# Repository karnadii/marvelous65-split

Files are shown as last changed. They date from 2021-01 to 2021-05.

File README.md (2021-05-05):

# Marvelous65 Split
ALL THE FILES MOVED TO https://github.com/karnadii/marvelous65

A split version of my marvelous65 keyboard. powered by pro micro or any compatible footprint like nice!nano and nrfmicro. This keyboard is wireless ready, I have added JST-XH connection for battery and an on off switch for the battery connection. It have encoder and oled on both side. also I have added underglow footprint if you want to add underglow in your keyboard. 

## Layout
try it at [KLE](http://www.keyboard-layout-editor.com/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'&_a:6&w:2.25%3B&=Enter&_x:1.75&a:7%3B&=%3B&@_w:1.25%3B&=&=&_x:1.75&a:6&w:2.25%3B&=Shift&_a:4%3B&=Z&=X&=C&=V&=B&_x:1%3B&=N&=M&=%3C%0A,&=%3E%0A.&=%3F%0A%2F%2F&_a:6&w:1.75%3B&=Shift%3B&@_y:-0.75&x:19.25&a:7%3B&=%E2%86%91%3B&@_y:-0.25&x:4&a:6&w:1.25%3B&=Ctrl&_w:1.25%3B&=Win&_w:1.25%3B&=Alt&_a:7&w:2.25%3B&=&_a:6&w:1.25%3B&=Fn2&_x:1&a:7&w:2.75%3B&=&_a:6%3B&=Alt&=Fn&=Ctrl%3B&@_y:-0.75&x:18.25&a:7%3B&=%E2%86%90&=%E2%86%93&=%E2%86%92%3B&@_x:15&w:1.5%3B&=&_w:1.5%3B&=)
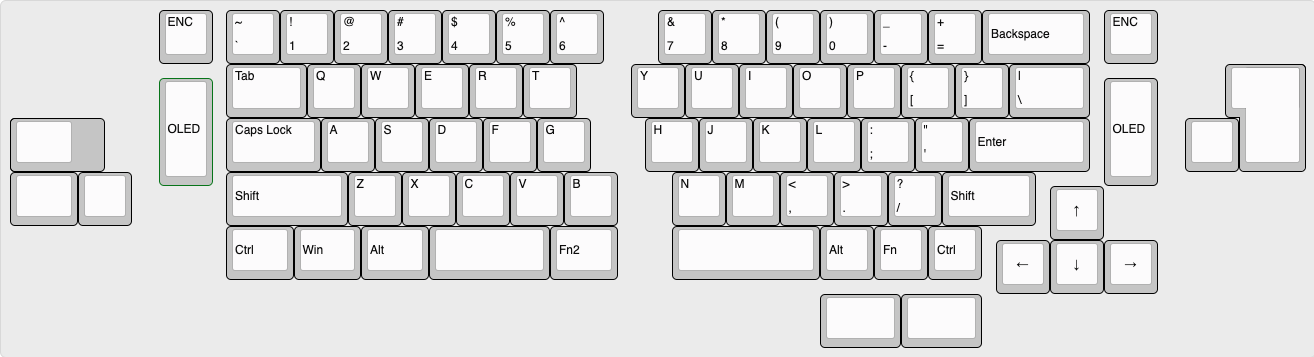
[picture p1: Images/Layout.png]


## Features
- Rotary Encoder
- 128x32 Oled display
- Wireless ready
- Promicro footprint 
- Optional RGB underglow (have to solder directly to mcu or desolder some resistor for pro micro. nice!nano and nrfmicro you can use unused pin)

## Firmware
For promicro you can use QMK and ZMK for wireless

## Case
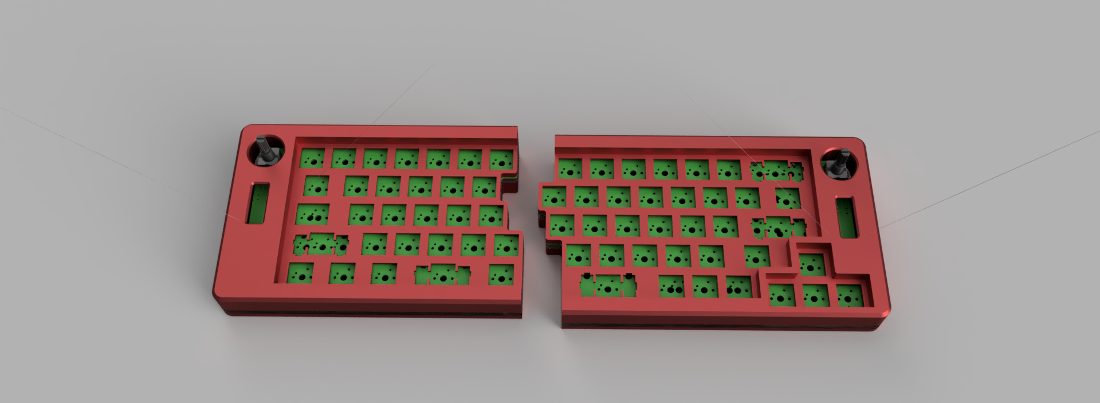
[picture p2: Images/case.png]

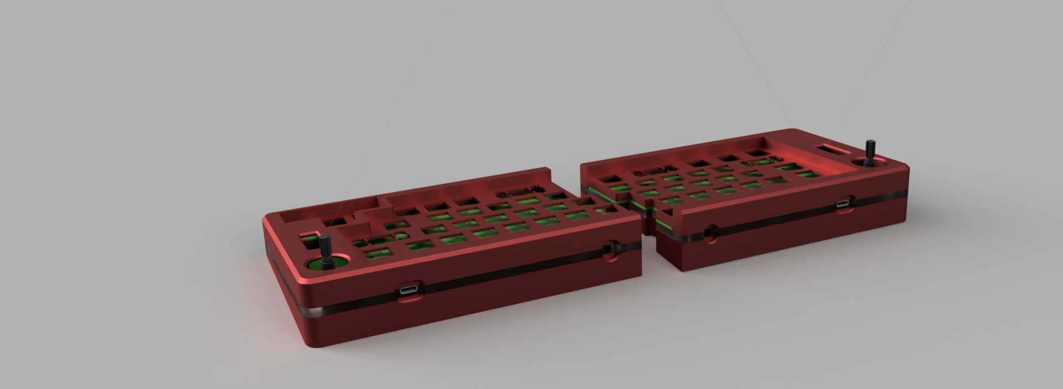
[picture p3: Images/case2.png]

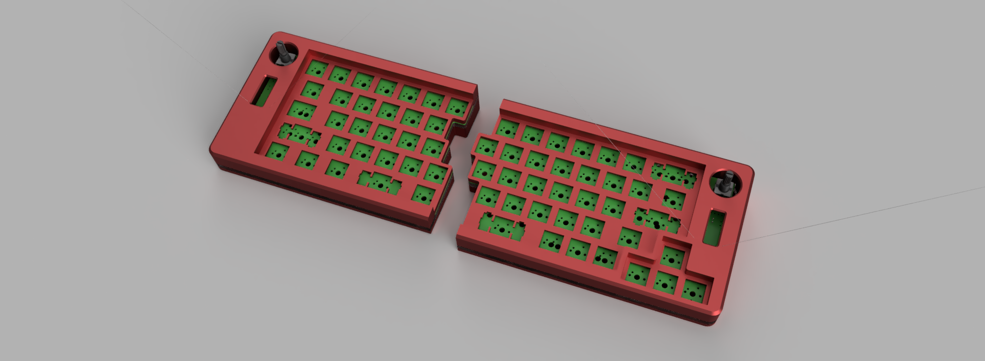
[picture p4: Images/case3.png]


## PCB
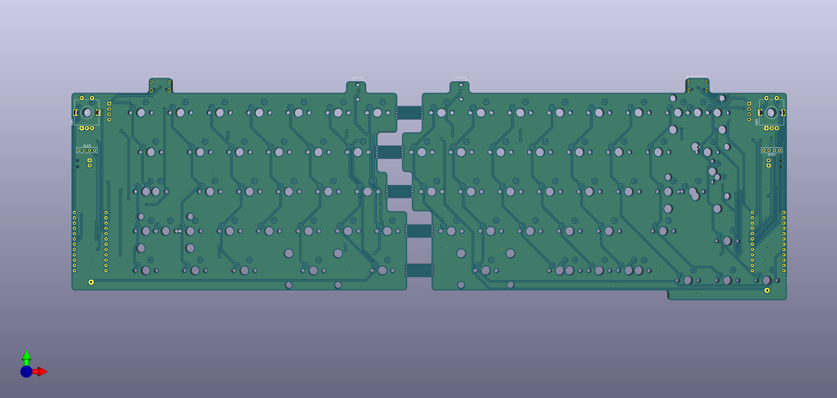
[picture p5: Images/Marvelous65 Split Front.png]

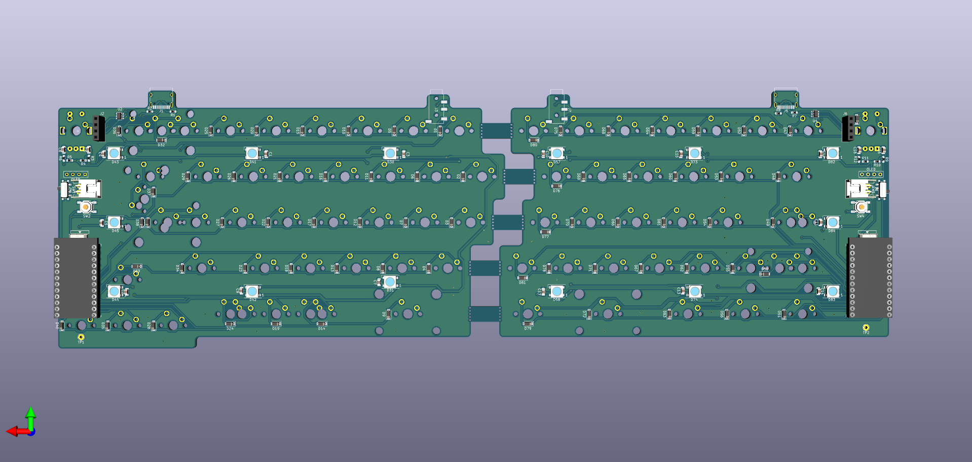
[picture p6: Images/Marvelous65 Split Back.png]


## Reference
This is my reference when designing the pcb
- https://github.com/Nicell/nice60

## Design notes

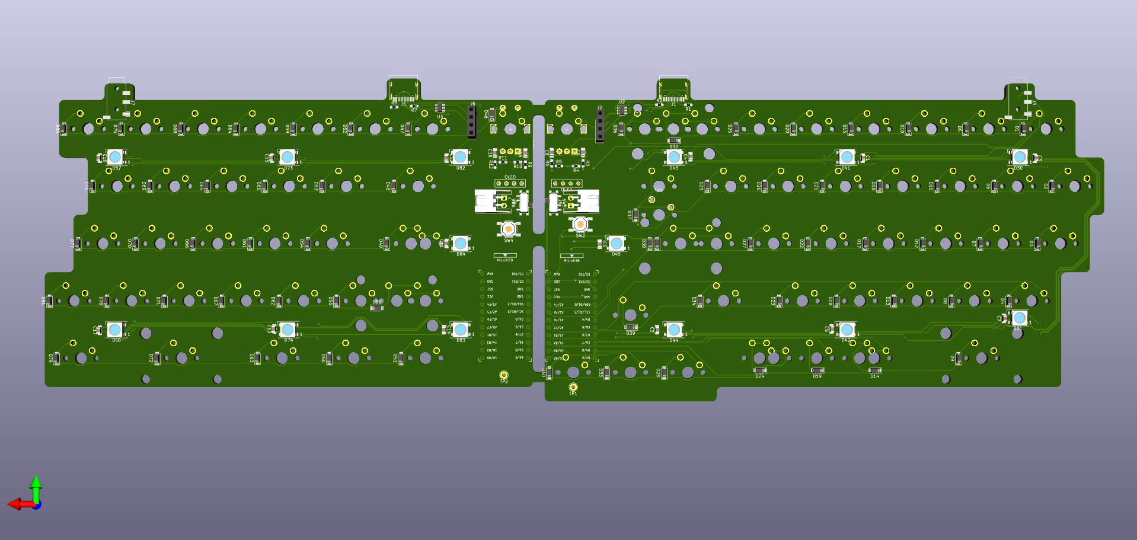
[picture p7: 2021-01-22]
Images/Marvelous65 Split.png

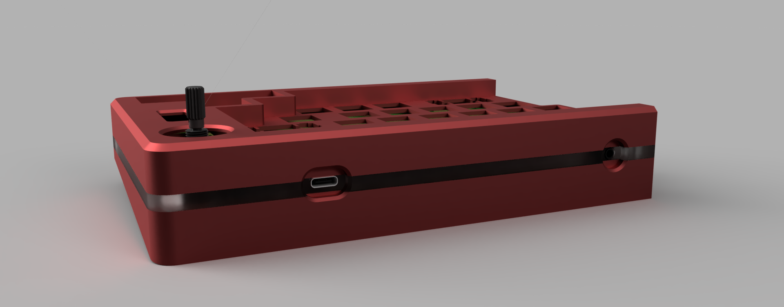
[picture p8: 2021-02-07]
PCB/Marvelous65_Split_Case_2021-Feb-07_12-52-04AM-000_CustomizedView30927780068.png

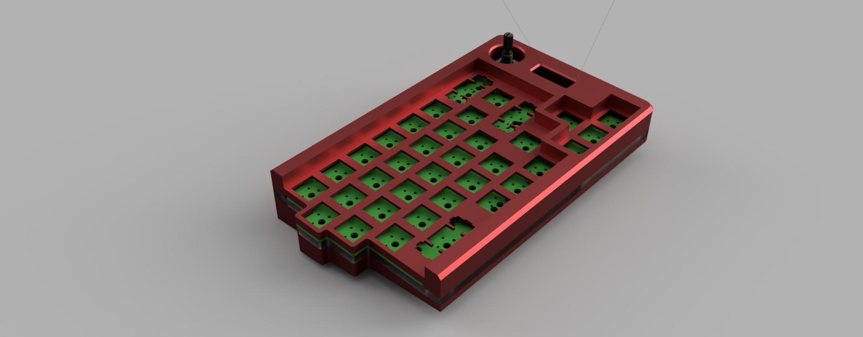
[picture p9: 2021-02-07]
PCB/Marvelous65_Split_Case_2021-Feb-07_12-53-03AM-000_CustomizedView2157800491.png

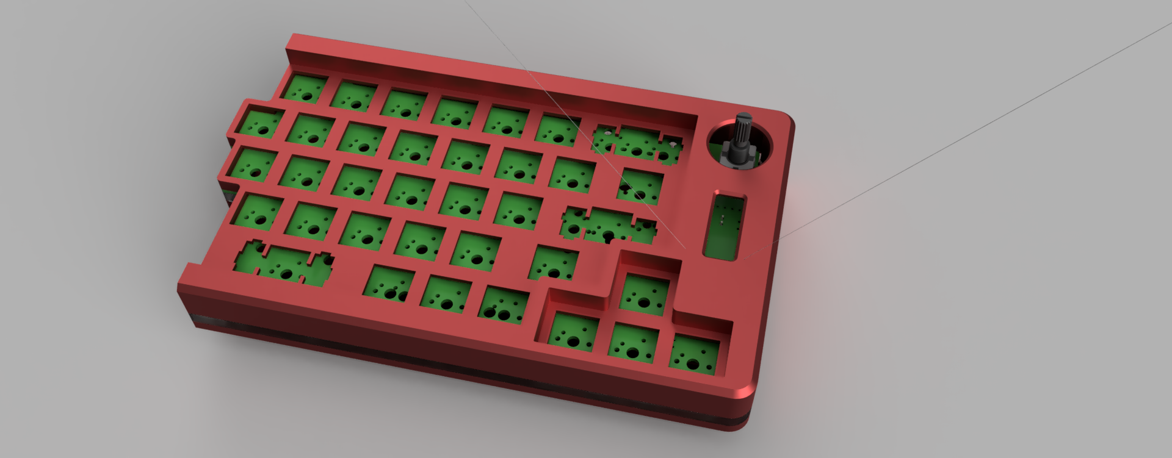
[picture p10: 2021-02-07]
PCB/Marvelous65_Split_Case_2021-Feb-07_12-50-50AM-000_CustomizedView4176303397.png

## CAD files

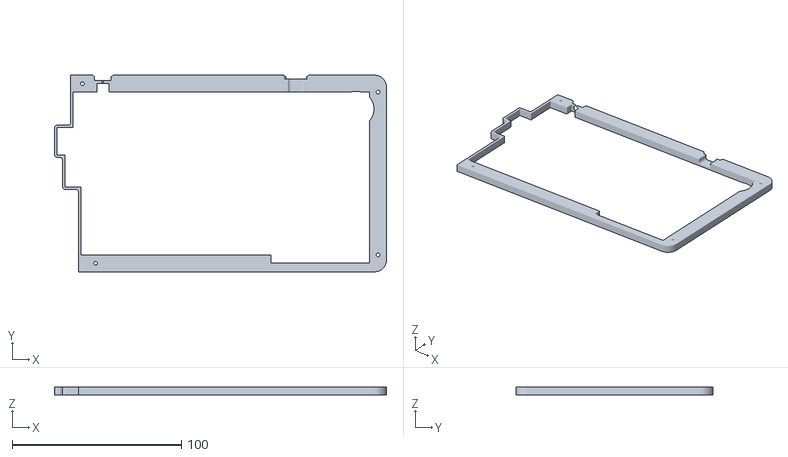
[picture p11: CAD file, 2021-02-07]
Case/Right middle case.stl
196.2 x 116.2 x 5.00

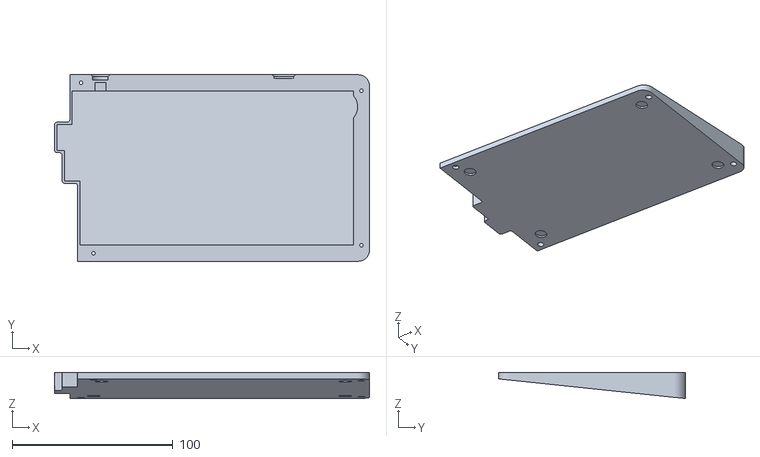
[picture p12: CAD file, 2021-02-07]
Case/Right bottom case.stl
196.2 x 116.2 x 16.2

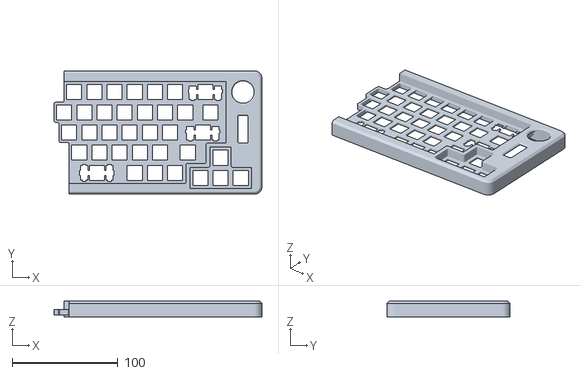
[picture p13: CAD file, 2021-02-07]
PCB/Top case.stl
196.2 x 116.2 x 14.7

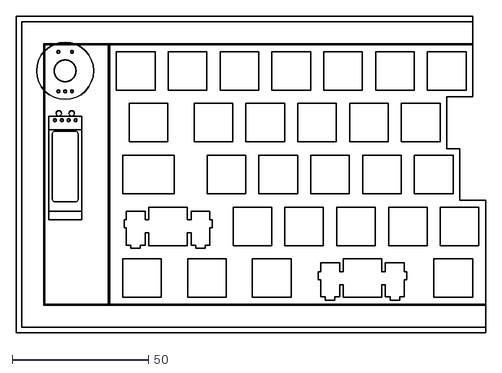
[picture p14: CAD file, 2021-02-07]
Sketch/Left Plate.dxf
172.4 x 116.3

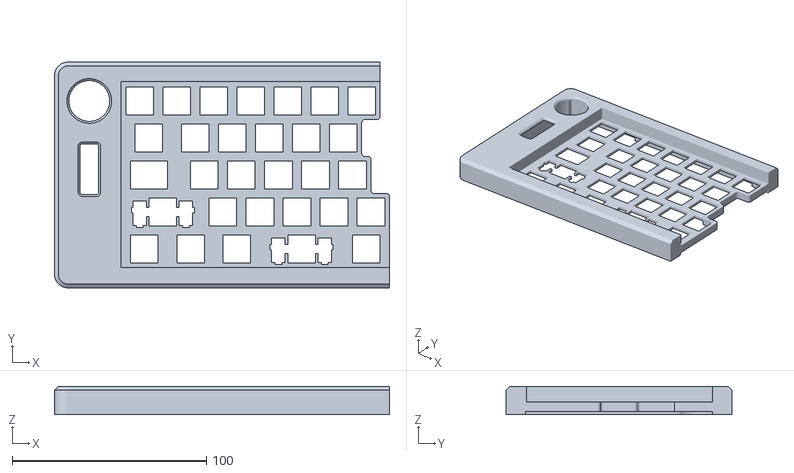
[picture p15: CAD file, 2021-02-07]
Case/Left top case.stl
172.4 x 116.3 x 14.6

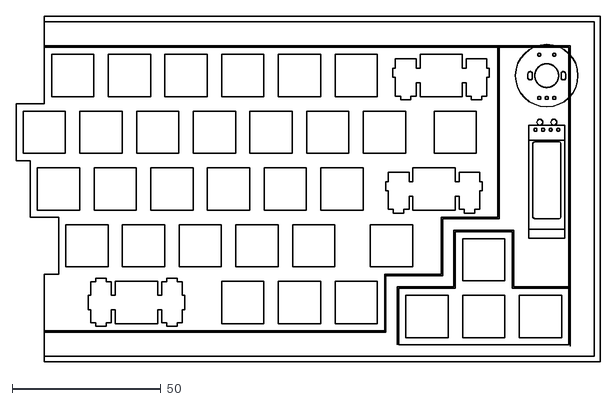
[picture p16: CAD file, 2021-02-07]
Sketch/Right plate.dxf
196.2 x 116.2

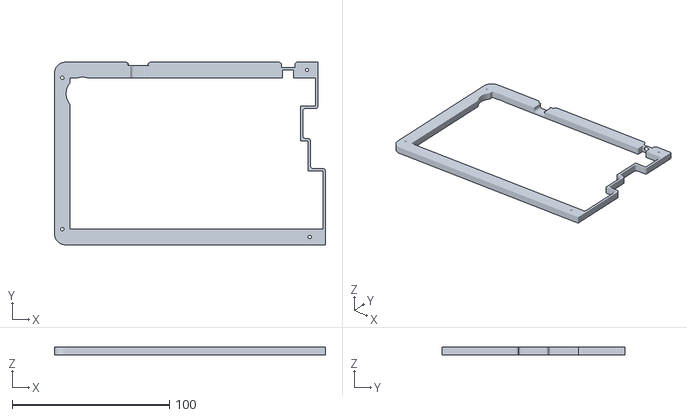
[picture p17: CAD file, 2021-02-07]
Case/Left middle case.stl
172.4 x 116.3 x 5.00

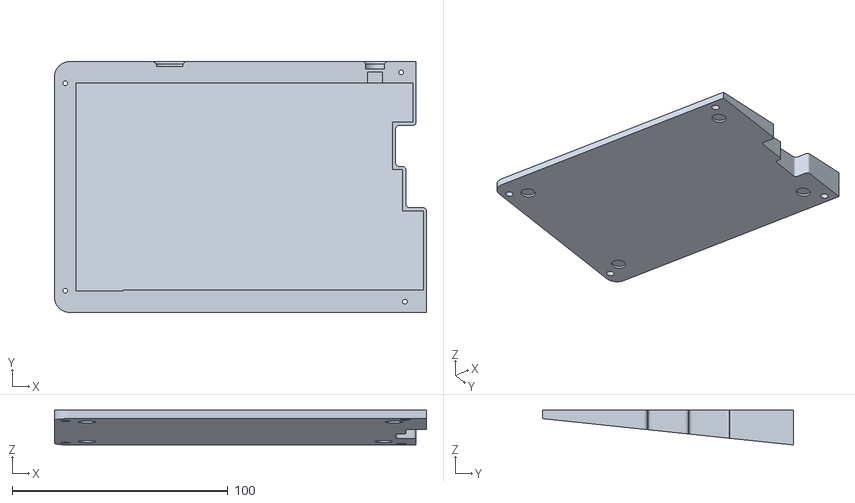
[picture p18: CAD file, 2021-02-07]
Case/left bottom case.stl
172.4 x 116.3 x 16.2

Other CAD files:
PCB/middle case.stl
Sketch/Right platsse.dwg
PCB/bottom case.stl
Case/Right Top case.stl
Sketch/Left Plate.dwg
Sketch/Right plate.dwg

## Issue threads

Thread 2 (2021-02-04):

Flipped connection on usb 4x1 pin

karnadii, 2021-02-04:
The square pad should be ground and not vbus. It is fine lea ing it as is. Bit it would be better to follow good practice.

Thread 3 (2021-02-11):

Move reset button and battery connector

karnadii, 2021-02-11:
The reset button, battery switch, and battery connector. It is hard to reach once assembled

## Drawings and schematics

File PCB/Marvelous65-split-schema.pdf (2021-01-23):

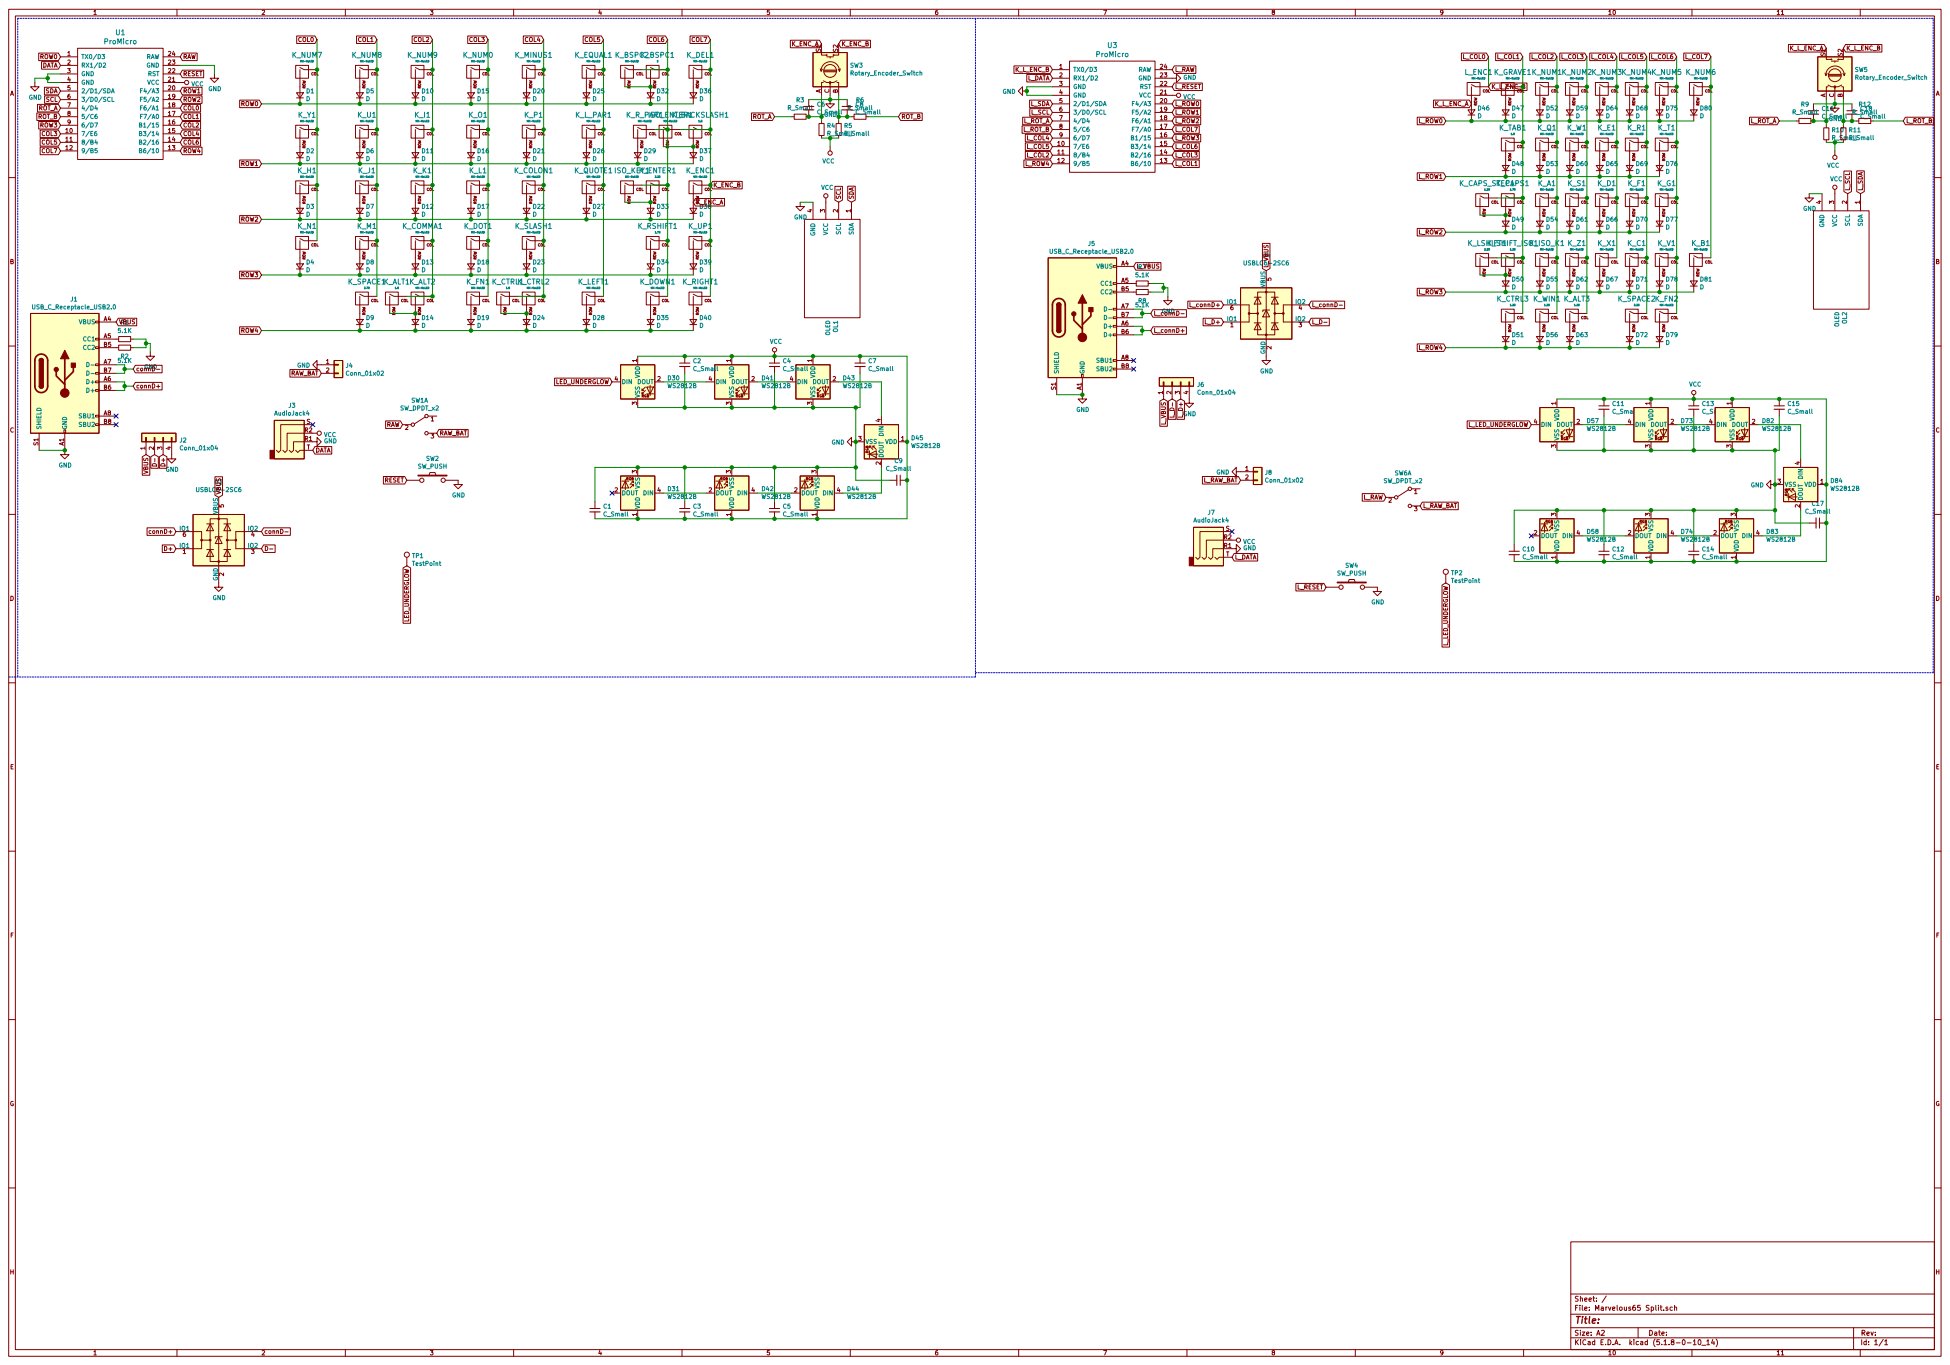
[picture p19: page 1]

MX-NoLED COL ROW

K_L_ENC_B

File: Marvelous65 Split.sch Sheet: /

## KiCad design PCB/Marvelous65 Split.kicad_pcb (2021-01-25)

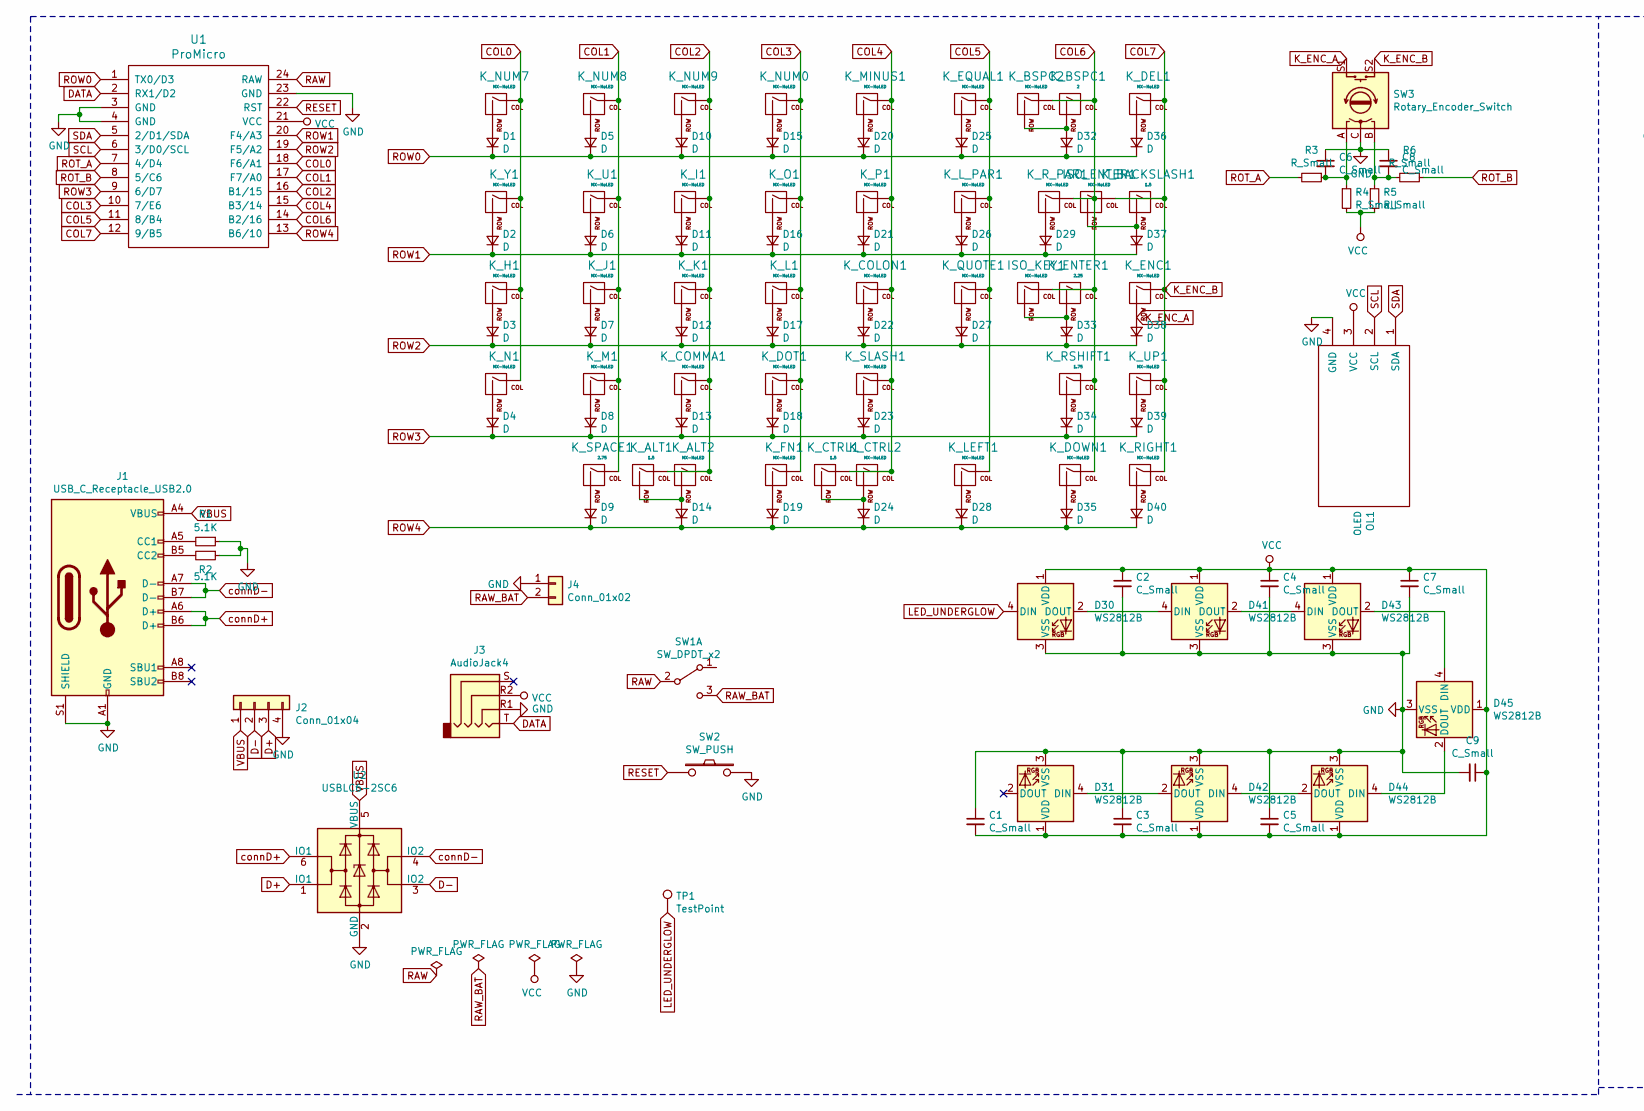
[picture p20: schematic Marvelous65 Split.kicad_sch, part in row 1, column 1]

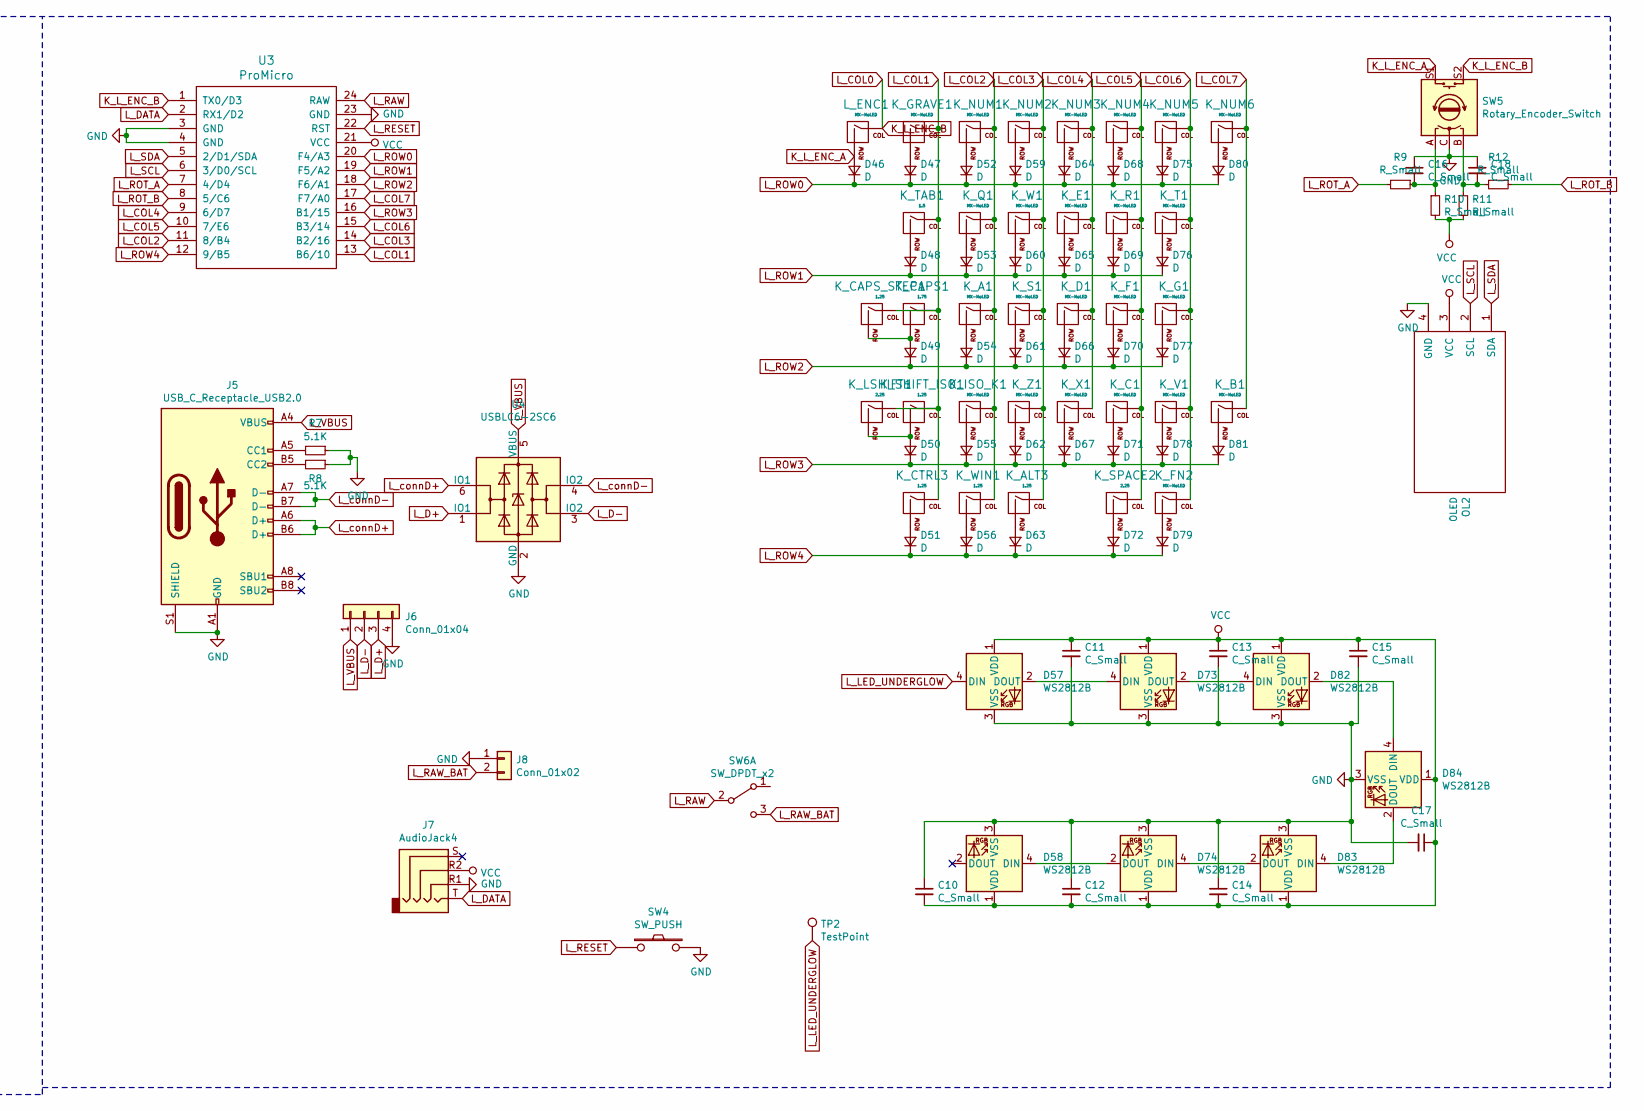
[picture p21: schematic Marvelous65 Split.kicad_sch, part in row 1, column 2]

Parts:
C1, C2, C3, C4, C5, C6, C7, C8, C9, C10, C11, C12, C13, C14, C15, C16, C17, C18: C_Small; C_0805_2012Metric_Pad1.15x1.40mm_HandSolder
D1, D2, D3, D4, D5, D6, D7, D8, D9, D10, D11, D12, D13, D14, D15, D16, D17, D18, D19, D20, D21, D22, D23, D24, D25, D26, D27, D28, D29, D32, D33, D34, D35, D36, D37, D38, D39, D40, D46, D47, D48, D49, D50, D51, D52, D53, D54, D55, D56, D59, D60, D61, D62, D63, D64, D65, D66, D67, D68, D69, D70, D71, D72, D75, D76, D77, D78, D79, D80, D81: D; D_SOD-123
D30, D31, D41, D42, D43, D44, D45, D57, D58, D73, D74, D82, D83, D84: WS2812B; LED_WS2812B_PLCC4_5.0x5.0mm_P3.2mm
ISO_ENTER1: MX-NoLED; MXOnly-ISO-ROTATED-ReversedStabilizers-NoLED
ISO_KEY1: MX-NoLED; MXOnly-1U-NoLED
J1, J5: USB_C_Receptacle_USB2.0; USB_C_Receptacle_HRO_TYPE-C-31-M-12
J2, J6: Conn_01x04; PinSocket_1x04_P2.54mm_Vertical
J3, J7: AudioJack4; Jack_3.5mm_PJ320D_Horizontal
J4, J8: Conn_01x02; JST_XH_S2B-XH-A_1x02_P2.50mm_Horizontal
K_A1: MX-NoLED; MXOnly-1U-NoLED
K_ALT1: 1.5; MXOnly-1.5U-NoLED
K_ALT2: MX-NoLED; MXOnly-1U-NoLED
K_ALT3: 1.25; MXOnly-1.25U-NoLED
K_B1: MX-NoLED; MXOnly-1U-NoLED
K_BACKSLASH1: 1.5; MXOnly-1.5U-NoLED
K_BSPC1: 2; MXOnly-2U-NoLED
K_BSPC2: MX-NoLED; MXOnly-1U-NoLED
K_C1: MX-NoLED; MXOnly-1U-NoLED
K_CAPS1: 1.75; MXOnly-1.75U-NoLED
K_CAPS_STEP1: 1.25; MXOnly-1.25U-NoLED
K_COLON1: MX-NoLED; MXOnly-1U-NoLED
K_COMMA1: MX-NoLED; MXOnly-1U-NoLED
K_CTRL1: 1.5; MXOnly-1.5U-NoLED
K_CTRL2: MX-NoLED; MXOnly-1U-NoLED
K_CTRL3: 1.25; MXOnly-1.25U-NoLED
K_D1: MX-NoLED; MXOnly-1U-NoLED
K_DEL1: MX-NoLED; MXOnly-1U-NoLED
K_DOT1: MX-NoLED; MXOnly-1U-NoLED
K_DOWN1: MX-NoLED; MXOnly-1U-NoLED
K_E1: MX-NoLED; MXOnly-1U-NoLED
K_ENC1: MX-NoLED; MXOnly-1U-NoLED
K_ENTER1: 2.25; MXOnly-2.25U-NoLED
K_EQUAL1: MX-NoLED; MXOnly-1U-NoLED
K_F1: MX-NoLED; MXOnly-1U-NoLED
K_FN1: MX-NoLED; MXOnly-1U-NoLED
K_FN2: MX-NoLED; MXOnly-1.25U-NoLED
K_G1: MX-NoLED; MXOnly-1U-NoLED
K_GRAVE1: MX-NoLED; MXOnly-1U-NoLED
K_H1: MX-NoLED; MXOnly-1U-NoLED
K_I1: MX-NoLED; MXOnly-1U-NoLED
K_ISO_K1: MX-NoLED; MXOnly-1U-NoLED
K_J1: MX-NoLED; MXOnly-1U-NoLED
K_K1: MX-NoLED; MXOnly-1U-NoLED
K_L1: MX-NoLED; MXOnly-1U-NoLED
K_LEFT1: MX-NoLED; MXOnly-1U-NoLED
K_LSHIFT1: 2.25; MXOnly-2.25U-NoLED
K_L_PAR1: MX-NoLED; MXOnly-1U-NoLED
K_M1: MX-NoLED; MXOnly-1U-NoLED
K_MINUS1: MX-NoLED; MXOnly-1U-NoLED
K_N1: MX-NoLED; MXOnly-1U-NoLED
K_NUM0, K_NUM1, K_NUM2, K_NUM3, K_NUM4, K_NUM5, K_NUM6, K_NUM7, K_NUM8, K_NUM9: MX-NoLED; MXOnly-1U-NoLED
K_O1: MX-NoLED; MXOnly-1U-NoLED
K_P1: MX-NoLED; MXOnly-1U-NoLED
K_Q1: MX-NoLED; MXOnly-1U-NoLED
K_QUOTE1: MX-NoLED; MXOnly-1U-NoLED
K_R1: MX-NoLED; MXOnly-1U-NoLED
K_RIGHT1: MX-NoLED; MXOnly-1U-NoLED
K_RSHIFT1: 1.75; MXOnly-1.75U-NoLED
K_R_PAR1: MX-NoLED; MXOnly-1U-NoLED
K_S1: MX-NoLED; MXOnly-1U-NoLED
K_SHIFT_ISO1: 1.25; MXOnly-1.25U-NoLED
K_SLASH1: MX-NoLED; MXOnly-1U-NoLED
K_SPACE1: 2.75; MXOnly-2.75U-ReversedStabilizers-NoLED
K_SPACE2: 2.25; MXOnly-2.25U-ReversedStabilizers-NoLED
K_T1: MX-NoLED; MXOnly-1U-NoLED
K_TAB1: 1.5; MXOnly-1.5U-NoLED
K_U1: MX-NoLED; MXOnly-1U-NoLED
K_UP1: MX-NoLED; MXOnly-1U-NoLED
K_V1: MX-NoLED; MXOnly-1U-NoLED
K_W1: MX-NoLED; MXOnly-1U-NoLED
K_WIN1: 1.25; MXOnly-1.25U-NoLED
K_X1: MX-NoLED; MXOnly-1U-NoLED
K_Y1: MX-NoLED; MXOnly-1U-NoLED
K_Z1: MX-NoLED; MXOnly-1U-NoLED
L_ENC1: MX-NoLED; MXOnly-1U-NoLED
OL1, OL2: OLED
R1, R2, R7, R8: 5.1K; R_0603_1608Metric_Pad1.05x0.95mm_HandSolder
R3, R4, R5, R6, R9, R10, R11, R12: R_Small; R_0603_1608Metric_Pad1.05x0.95mm_HandSolder
SW1, SW6: SW_DPDT_x2; SW_SPDT_PCM12
SW2, SW4: SW_PUSH; SW_SPST_TL3342
SW3, SW5: Rotary_Encoder_Switch; RotaryEncoder_Alps_EC11E-Switch_Vertical_H20mm
TP1, TP2: TestPoint; TestPoint_THTPad_D2.5mm_Drill1.2mm
U1, U3: ProMicro; ProMicro_v3
U2, U4: USBLC6-2SC6; SOT-23-6

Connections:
COL0: K_H1.1 (COL), K_N1.1 (COL), K_NUM7.1 (COL), K_Y1.1 (COL), U1.18 (F6/A1)
COL1: K_J1.1 (COL), K_M1.1 (COL), K_NUM8.1 (COL), K_SPACE1.1 (COL), K_U1.1 (COL), U1.17 (F7/A0)
COL2: K_ALT1.1 (COL), K_ALT2.1 (COL), K_COMMA1.1 (COL), K_I1.1 (COL), K_K1.1 (COL), K_NUM9.1 (COL), U1.16 (B1/15)
COL3: K_DOT1.1 (COL), K_FN1.1 (COL), K_L1.1 (COL), K_NUM0.1 (COL), K_O1.1 (COL), U1.10 (7/E6)
COL4: K_COLON1.1 (COL), K_CTRL1.1 (COL), K_CTRL2.1 (COL), K_MINUS1.1 (COL), K_P1.1 (COL), K_SLASH1.1 (COL), U1.15 (B3/14)
COL5: K_EQUAL1.1 (COL), K_LEFT1.1 (COL), K_L_PAR1.1 (COL), K_QUOTE1.1 (COL), U1.11 (8/B4)
COL6: ISO_KEY1.1 (COL), K_BSPC1.1 (COL), K_BSPC2.1 (COL), K_DOWN1.1 (COL), K_ENTER1.1 (COL), K_RSHIFT1.1 (COL), K_R_PAR1.1 (COL), U1.14 (B2/16)
COL7: ISO_ENTER1.1 (COL), K_BACKSLASH1.1 (COL), K_DEL1.1 (COL), K_ENC1.1 (COL), K_RIGHT1.1 (COL), K_UP1.1 (COL), SW3.S2, U1.12 (9/B5)
D+: J2.3, U2.1 (IO1)
D-: J2.2, U2.3 (IO2)
DATA: J3.T, U1.2 (RX1/D2)
GND: C1.1, C2.2, C3.1, C4.2, C5.1, C6.1, C7.2, C8.1, C9.2, C10.1, C11.2, C12.1, C13.2, C14.1, C15.2, C16.1, C17.2, C18.1, D30.3 (VSS), D31.3 (VSS), D41.3 (VSS), D42.3 (VSS), D43.3 (VSS), D44.3 (VSS), D45.3 (VSS), D57.3 (VSS), D58.3 (VSS), D73.3 (VSS), D74.3 (VSS), D82.3 (VSS), D83.3 (VSS), D84.3 (VSS), J1.A1 (GND), J1.A12 (GND), J1.B1 (GND), J1.B12 (GND), J1.S1 (SHIELD), J2.4, J3.R1, J4.1, J5.A1 (GND), J5.A12 (GND), J5.B1 (GND), J5.B12 (GND), J5.S1 (SHIELD), J6.4, J7.R1, J8.1, OL1.4 (GND), OL2.4 (GND), R1.1, R2.1, R7.1, R8.1, SW2.2, SW3.C, SW4.2, SW5.C, U1.3 (GND), U1.4 (GND), U1.23 (GND), U2.2 (GND), U3.3 (GND), U3.4 (GND), U3.23 (GND), U4.2 (GND)
K_ENC_A: D38.2 (A), K_ENC1.2 (ROW), SW3.S1
K_L_ENC_A: D46.2 (A), L_ENC1.2 (ROW), SW5.S1
K_L_ENC_B: L_ENC1.1 (COL), SW5.S2, U3.1 (TX0/D3)
LED_UNDERGLOW: D30.4 (DIN), TP1.1
L_COL1: K_CAPS1.1 (COL), K_CAPS_STEP1.1 (COL), K_CTRL3.1 (COL), K_GRAVE1.1 (COL), K_LSHIFT1.1 (COL), K_SHIFT_ISO1.1 (COL), K_TAB1.1 (COL), U3.13 (B6/10)
L_COL2: K_A1.1 (COL), K_ISO_K1.1 (COL), K_NUM1.1 (COL), K_Q1.1 (COL), K_WIN1.1 (COL), U3.11 (8/B4)
L_COL3: K_ALT3.1 (COL), K_NUM2.1 (COL), K_S1.1 (COL), K_W1.1 (COL), K_Z1.1 (COL), U3.14 (B2/16)
L_COL4: K_D1.1 (COL), K_E1.1 (COL), K_NUM3.1 (COL), K_X1.1 (COL), U3.9 (6/D7)
L_COL5: K_C1.1 (COL), K_F1.1 (COL), K_NUM4.1 (COL), K_R1.1 (COL), K_SPACE2.1 (COL), U3.10 (7/E6)
L_COL6: K_FN2.1 (COL), K_G1.1 (COL), K_NUM5.1 (COL), K_T1.1 (COL), K_V1.1 (COL), U3.15 (B3/14)
L_COL7: K_B1.1 (COL), K_NUM6.1 (COL), U3.17 (F7/A0)
L_D+: J6.3, U4.1 (IO1)
L_D-: J6.2, U4.3 (IO2)
L_DATA: J7.T, U3.2 (RX1/D2)
L_LED_UNDERGLOW: D57.4 (DIN), TP2.1
L_RAW: SW6.2 (B), U3.24 (RAW)
L_RAW_BAT: J8.2, SW6.3 (C)
L_RESET: SW4.1, U3.22 (RST)
L_ROT_A: R9.2, U3.7 (4/D4)
L_ROT_B: R12.1, U3.8 (5/C6)
L_ROW0: D46.1 (K), D47.1 (K), D52.1 (K), D59.1 (K), D64.1 (K), D68.1 (K), D75.1 (K), D80.1 (K), U3.20 (F4/A3)
L_ROW1: D48.1 (K), D53.1 (K), D60.1 (K), D65.1 (K), D69.1 (K), D76.1 (K), U3.19 (F5/A2)
L_ROW2: D49.1 (K), D54.1 (K), D61.1 (K), D66.1 (K), D70.1 (K), D77.1 (K), U3.18 (F6/A1)
L_ROW3: D50.1 (K), D55.1 (K), D62.1 (K), D67.1 (K), D71.1 (K), D78.1 (K), D81.1 (K), U3.16 (B1/15)
L_ROW4: D51.1 (K), D56.1 (K), D63.1 (K), D72.1 (K), D79.1 (K), U3.12 (9/B5)
L_SCL: OL2.2 (SCL), U3.6 (3/D0/SCL)
L_SDA: OL2.1 (SDA), U3.5 (2/D1/SDA)
L_VBUS: J5.A4 (VBUS), J5.A9 (VBUS), J5.B4 (VBUS), J5.B9 (VBUS), J6.1, U4.5 (VBUS)
L_connD+: J5.A6 (D+), J5.B6 (D+), U4.6 (IO1)
L_connD-: J5.A7 (D-), J5.B7 (D-), U4.4 (IO2)
unnamed: C6.2, R3.1, R4.1, SW3.A
unnamed: C8.2, R5.1, R6.2, SW3.B
unnamed: C16.2, R9.1, R10.1, SW5.A
unnamed: C18.2, R11.1, R12.2, SW5.B
unnamed: D1.2 (A), K_NUM7.2 (ROW)
unnamed: D2.2 (A), K_Y1.2 (ROW)
unnamed: D3.2 (A), K_H1.2 (ROW)
unnamed: D4.2 (A), K_N1.2 (ROW)
unnamed: D5.2 (A), K_NUM8.2 (ROW)
unnamed: D6.2 (A), K_U1.2 (ROW)
unnamed: D7.2 (A), K_J1.2 (ROW)
unnamed: D8.2 (A), K_M1.2 (ROW)
unnamed: D9.2 (A), K_SPACE1.2 (ROW)
unnamed: D10.2 (A), K_NUM9.2 (ROW)
unnamed: D11.2 (A), K_I1.2 (ROW)
unnamed: D12.2 (A), K_K1.2 (ROW)
unnamed: D13.2 (A), K_COMMA1.2 (ROW)
unnamed: D14.2 (A), K_ALT1.2 (ROW), K_ALT2.2 (ROW)
unnamed: D15.2 (A), K_NUM0.2 (ROW)
unnamed: D16.2 (A), K_O1.2 (ROW)
unnamed: D17.2 (A), K_L1.2 (ROW)
unnamed: D18.2 (A), K_DOT1.2 (ROW)
unnamed: D19.2 (A), K_FN1.2 (ROW)
unnamed: D20.2 (A), K_MINUS1.2 (ROW)
unnamed: D21.2 (A), K_P1.2 (ROW)
unnamed: D22.2 (A), K_COLON1.2 (ROW)
unnamed: D23.2 (A), K_SLASH1.2 (ROW)
unnamed: D24.2 (A), K_CTRL1.2 (ROW), K_CTRL2.2 (ROW)
unnamed: D25.2 (A), K_EQUAL1.2 (ROW)
unnamed: D26.2 (A), K_L_PAR1.2 (ROW)
unnamed: D27.2 (A), K_QUOTE1.2 (ROW)
unnamed: D28.2 (A), K_LEFT1.2 (ROW)
unnamed: D29.2 (A), K_R_PAR1.2 (ROW)
unnamed: D30.2 (DOUT), D41.4 (DIN)
unnamed: D31.4 (DIN), D42.2 (DOUT)
unnamed: D32.2 (A), K_BSPC1.2 (ROW), K_BSPC2.2 (ROW)
unnamed: D33.2 (A), ISO_KEY1.2 (ROW), K_ENTER1.2 (ROW)
unnamed: D34.2 (A), K_RSHIFT1.2 (ROW)
unnamed: D35.2 (A), K_DOWN1.2 (ROW)
unnamed: D36.2 (A), K_DEL1.2 (ROW)
unnamed: D37.2 (A), ISO_ENTER1.2 (ROW), K_BACKSLASH1.2 (ROW)
unnamed: D39.2 (A), K_UP1.2 (ROW)
unnamed: D40.2 (A), K_RIGHT1.2 (ROW)
unnamed: D41.2 (DOUT), D43.4 (DIN)
unnamed: D42.4 (DIN), D44.2 (DOUT)
unnamed: D43.2 (DOUT), D45.4 (DIN)
unnamed: D44.4 (DIN), D45.2 (DOUT)
unnamed: D47.2 (A), K_GRAVE1.2 (ROW)
unnamed: D48.2 (A), K_TAB1.2 (ROW)
unnamed: D49.2 (A), K_CAPS1.2 (ROW), K_CAPS_STEP1.2 (ROW)
unnamed: D50.2 (A), K_LSHIFT1.2 (ROW), K_SHIFT_ISO1.2 (ROW)
unnamed: D51.2 (A), K_CTRL3.2 (ROW)
unnamed: D52.2 (A), K_NUM1.2 (ROW)
unnamed: D53.2 (A), K_Q1.2 (ROW)
unnamed: D54.2 (A), K_A1.2 (ROW)
unnamed: D55.2 (A), K_ISO_K1.2 (ROW)
unnamed: D56.2 (A), K_WIN1.2 (ROW)
unnamed: D57.2 (DOUT), D73.4 (DIN)
unnamed: D58.4 (DIN), D74.2 (DOUT)
unnamed: D59.2 (A), K_NUM2.2 (ROW)
unnamed: D60.2 (A), K_W1.2 (ROW)
unnamed: D61.2 (A), K_S1.2 (ROW)
unnamed: D62.2 (A), K_Z1.2 (ROW)
unnamed: D63.2 (A), K_ALT3.2 (ROW)
unnamed: D64.2 (A), K_NUM3.2 (ROW)
unnamed: D65.2 (A), K_E1.2 (ROW)
unnamed: D66.2 (A), K_D1.2 (ROW)
unnamed: D67.2 (A), K_X1.2 (ROW)
unnamed: D68.2 (A), K_NUM4.2 (ROW)
unnamed: D69.2 (A), K_R1.2 (ROW)
unnamed: D70.2 (A), K_F1.2 (ROW)
unnamed: D71.2 (A), K_C1.2 (ROW)
unnamed: D72.2 (A), K_SPACE2.2 (ROW)
unnamed: D73.2 (DOUT), D82.4 (DIN)
unnamed: D74.4 (DIN), D83.2 (DOUT)
unnamed: D75.2 (A), K_NUM5.2 (ROW)
unnamed: D76.2 (A), K_T1.2 (ROW)
unnamed: D77.2 (A), K_G1.2 (ROW)
unnamed: D78.2 (A), K_V1.2 (ROW)
unnamed: D79.2 (A), K_FN2.2 (ROW)
unnamed: D80.2 (A), K_NUM6.2 (ROW)
unnamed: D81.2 (A), K_B1.2 (ROW)
unnamed: D82.2 (DOUT), D84.4 (DIN)
unnamed: D83.4 (DIN), D84.2 (DOUT)
unnamed: J1.A5 (CC1), R1.2
unnamed: J1.B5 (CC2), R2.2
unnamed: J5.A5 (CC1), R7.2
unnamed: J5.B5 (CC2), R8.2
RAW: SW1.2 (B), U1.24 (RAW)
RAW_BAT: J4.2, SW1.3 (C)
RESET: SW2.1, U1.22 (RST)
ROT_A: R3.2, U1.7 (4/D4)
ROT_B: R6.1, U1.8 (5/C6)
ROW0: D1.1 (K), D5.1 (K), D10.1 (K), D15.1 (K), D20.1 (K), D25.1 (K), D32.1 (K), D36.1 (K), U1.1 (TX0/D3)
ROW1: D2.1 (K), D6.1 (K), D11.1 (K), D16.1 (K), D21.1 (K), D26.1 (K), D29.1 (K), D37.1 (K), U1.20 (F4/A3)
ROW2: D3.1 (K), D7.1 (K), D12.1 (K), D17.1 (K), D22.1 (K), D27.1 (K), D33.1 (K), D38.1 (K), U1.19 (F5/A2)
ROW3: D4.1 (K), D8.1 (K), D13.1 (K), D18.1 (K), D23.1 (K), D34.1 (K), D39.1 (K), U1.9 (6/D7)
ROW4: D9.1 (K), D14.1 (K), D19.1 (K), D24.1 (K), D28.1 (K), D35.1 (K), D40.1 (K), U1.13 (B6/10)
SCL: OL1.2 (SCL), U1.6 (3/D0/SCL)
SDA: OL1.1 (SDA), U1.5 (2/D1/SDA)
VBUS: J1.A4 (VBUS), J1.A9 (VBUS), J1.B4 (VBUS), J1.B9 (VBUS), J2.1, U2.5 (VBUS)
VCC: C1.2, C2.1, C3.2, C4.1, C5.2, C7.1, C9.1, C10.2, C11.1, C12.2, C13.1, C14.2, C15.1, C17.1, D30.1 (VDD), D31.1 (VDD), D41.1 (VDD), D42.1 (VDD), D43.1 (VDD), D44.1 (VDD), D45.1 (VDD), D57.1 (VDD), D58.1 (VDD), D73.1 (VDD), D74.1 (VDD), D82.1 (VDD), D83.1 (VDD), D84.1 (VDD), J3.R2, J7.R2, OL1.3 (VCC), OL2.3 (VCC), R4.2, R5.2, R10.2, R11.2, U1.21 (VCC), U3.21 (VCC)
connD+: J1.A6 (D+), J1.B6 (D+), U2.6 (IO1)
connD-: J1.A7 (D-), J1.B7 (D-), U2.4 (IO2)

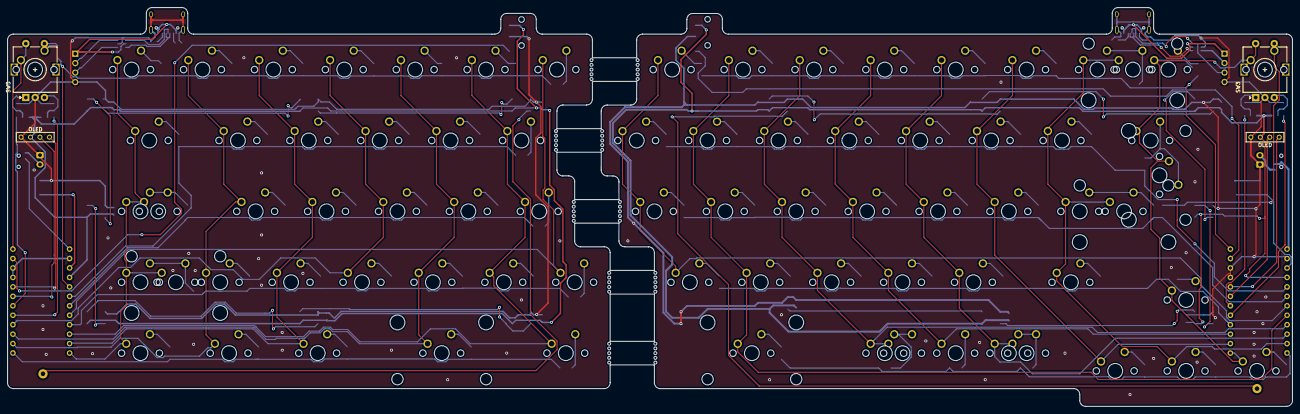
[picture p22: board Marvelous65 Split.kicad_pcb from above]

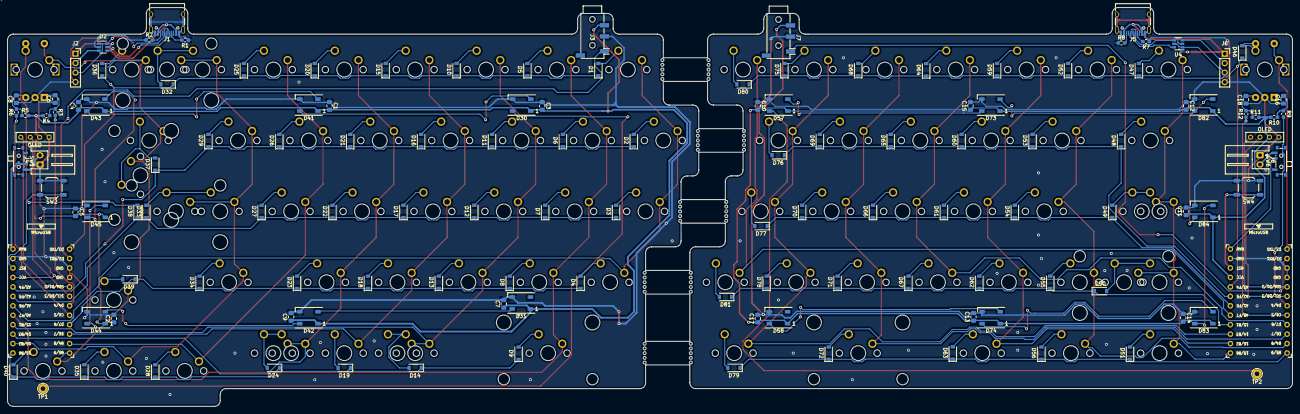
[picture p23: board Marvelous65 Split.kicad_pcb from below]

Board: 2 copper layers, 345.3 x 107.2 mm, 213 parts (133 on the bottom side), 146 nets.

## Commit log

2021-01-22 add pcb
    [Marvelous65 Split left.sch, Marvelous65 Split.kicad_pcb, Marvelous65 Split.sch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]
2021-01-22 generate gerber
    [Marvelous65 Split left.sch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]
2021-01-23 fix iso enter and panelization
    [Marvelous65 Split.kicad_pcb, Marvelous65 Split.sch]
2021-01-23 updated rendered images
    [Marvelous65 Split.kicad_pcb]
2021-01-23 add schematic and gerber
    [Marvelous65 Split.kicad_pcb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]
2021-01-25 update breakout method
    [Marvelous65 Split.kicad_pcb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]
2021-01-25 update gerber
2021-02-07 add a bunch of files
    [Left Plate.dwg, Left Plate.dxf, Left middle case.stl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]
2021-02-12 add sketch file
    [Left Plate.dwg, Right plate.dwg, Right platsse.dwg]
